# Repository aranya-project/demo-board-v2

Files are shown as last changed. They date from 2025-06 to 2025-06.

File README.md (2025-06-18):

# SpiderOak Demo V2 Board

This is a demonstration board for [Aranya
Embedded](https://github.com/aranya-project/aranya-embedded) built around the
ESP32-S3. It provides various peripheral options used by the [Aranya Embedded
demo](https://github.com/aranya-project/aranya-embedded/crates/demo-esp32-s3/).

## Board View

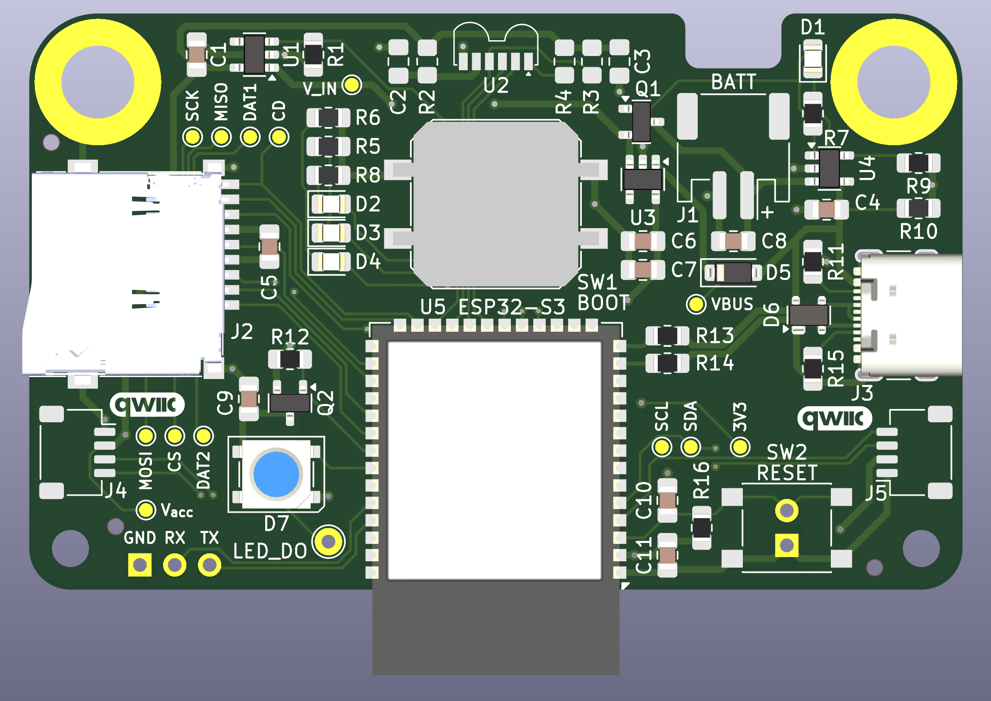
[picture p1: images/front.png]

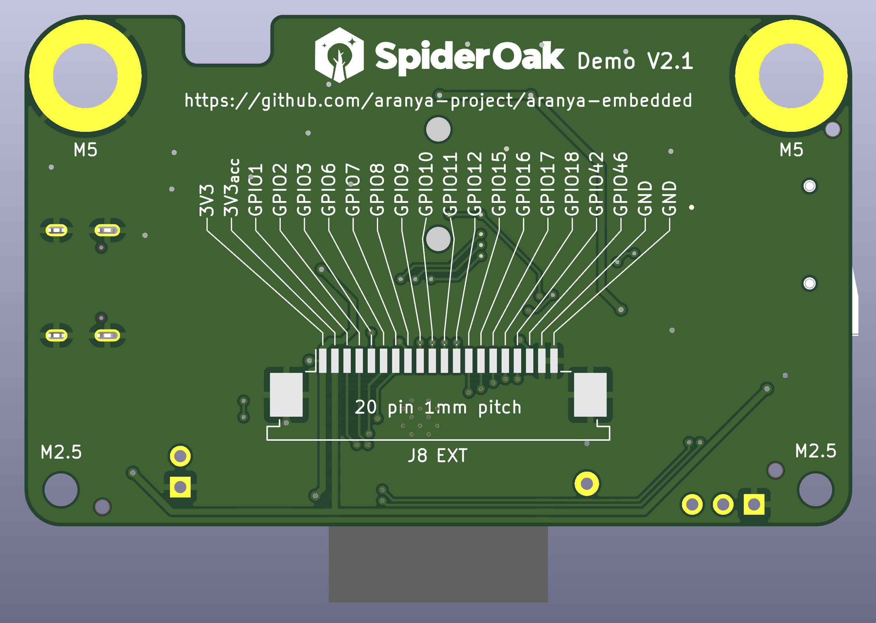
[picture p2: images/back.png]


## Assembly Options

The IR transceiver U2 is necessary if you intend ot use IR networking. It uses
the Vishay TFBS4711 which is somewhat pricey, so it has not been included by
default.

The battery jack is a 2mm pitch JST PH connector, and the Qwiic connectors are
1mm pitch JST SH connectors. The RGB LED is a WS2812 5mm LED module. The SD card
slot is a SameSky MSD-4-A, and the USB jack is a GCT USB4105. If you search
around you will find many alternatives for these as they are very commonly used.

A footprint is provided but not populated for reset switch - a SMD 6mm tactile
switch (Omron B3FS or similar). Likewise there is an unpopulated 20pin expansion
header on the back - details on that [below](#test-points-and-expansion).

## Power

Input power comes from either the battery or the USB input. A schottky diode and
a P-channel MOSFET (D5 and Q1) switch power between them and prevent USB power
from backfeeding into the battery. The battery is charged by a standard 500mA
5-pin single-cell lithium linear charge controller (TPS4054/MCP73831/etc), and
LED D1 will light when charging is complete.

The ESP32 is powered by a primary 3.3V regulator (the TLV74333), and all other
devices (IR transceiver, SD card slot, and any Qwiic accessories) are powered
by a secondary 3.3V regulator enabled by a high output on GPIO 47.

Separately, power to the RGB LED is switched via an open drain output on GPIO
40. This pin must be brought low to turn on the P-channel MOSFET controlling
power to the LED. The LED power is connected to input power (either the USB or
battery) directly, so it is not controlled by the accessory power regulator.

### Pin Summary

| GPIO Pin | Function | Operation |
|---|---|---|
| 47 | Accessory power enable | output, active high |
| 40 | LED power enable | open drain output, active low |

## IR Transceivers

IR1 is connected to UART1 TX/RX on pins on GPIOs 13 and 14, respectively. The IR
transceiver has to be enabled with a low output on GPIO 21.

Enabling IrDA mode requires setting `UART_IRDA_EN` in `UART_CONF0_REG`.
Additionally, to transmit, you need to set `UART_IRDA_TX_EN`. By default, IrDA
mode is half duplex, and `UART_IRDA_TX_EN` needs to be toggled to switch between
transmit and receive modes. To enable both transmit and receive at the same
time, which will echo all transmitted data through the RX line, set
`UART_IRDA_DPLX`.

For reasons I don't understand, the only thing that can be set via IDF APIs is
enabling IrDA mode. All of the other IrDA settings are not available via IDF
APIs, so you will likely have to twiddle the registers directly. In C, this can
be done by including `soc/uart_struct.h` and using the bitfield structs
provided. e.g.

```
UART1.conf0.irda_dplx = 1;
```

### Pin Summary

| GPIO Pin | Function | Operation |
|---|---|---|
| 13 | Transmit | output |
| 14 | Receive | input |
| 21 | Enable | output, active low |

## Micro SD

The SD card is connected to SPI such that it should be usable directly
through the IOMUX on IOs 35, 36, and 37. CS is connected to GPIO 38.
The slot has card detect functionality, which is connected to GPIO 48.

Additionally, DAT1 and DAT2 (only used in SD mode) are connected to
GPIOs 45 and 39, respectively, so you should theoretically be able to
enable 4-bit SD through the SD/MMC controller.

### Pin Summary (SPI mode)

| GPIO Pin | Function | Operation |
|---|---|---|
| 36 | SCK | output |
| 35 | MOSI | output |
| 37 | MISO | input |
| 38 | CS | output |

### Pin Summary (SD 1-bit mode)

| GPIO Pin | Function | Operation |
|---|---|---|
| 36 | CLK | output |
| 35 | CMD | input/output |
| 37 | DAT0 | input/output |
| 38 | CD | input |

### Pin Summary (SD 4-bit mode)

| GPIO Pin | Function | Operation |
|---|---|---|
| 36 | CLK | output |
| 35 | CMD | input/output |
| 37 | DAT0 | input/output |
| 45 | DAT1 | input/output |
| 39 | DAT2 | input/output |
| 38 | DAT3 | input/output |

### Pin Summary (card detect)

| GPIO Pin | Function | Operation |
|---|---|---|
| 48 | card detect | input, pull-up, active low |

## Debug LEDs

Three LEDs are hooked up to GPIOs 10-12, and can be used for any purpose.

### Pin Summary

| GPIO Pin | Function | Operation |
|---|---|---|
| 10 | Debug LED 1 | output, active high |
| 11 | Debug LED 2 | output, active high |
| 12 | Debug LED 3 | output, active high |

## Test points and expansion

The unused GPIOs 1-3, 6-9, 15-18, 42, and 46; the debug LED GPIOs 10-12; as
well as the main and accessory 3.3V regulators; and GND are broken out via a
20-pin 1mm pitch flat flex footprint on the back. You can either install a flat
flex connector or wire directly to the pads.

Test points are provided for VBUS (USB power), V_IN (OR'd power between VBUS and
VBATT), main 3V3, V<sub>acc</sub> (accessory power), SCL/SDA connected to the
Qwiic ports, and SCK, MOSI, MISO, CS, DAT1, DAT2 and CD on the SD card slot.

A three-pin 0.1" header is available for TX, RX, and GND for UART0, and a single
pin header is available for the DO pin on the WS2812 LED module. There are also
0.1" pin headers for the reset switch inside the tactile switch footprint.

## Mechanical

The board is 68mm wide and 42mm tall (2.68 x 1.66 inches). The ESP32-S3 module's
antenna hangs off of the bottom of the board, making the full height 48.4mm
(1.91 inches).

At the top are two M5 sized plated holes meant to accomodate lanyard hooks. They
are centered 5mm from the edges. At the bottom are two more M2.5 holes for any
other mounting needs, centered 3mm from the edges.

A 7x4mm cutout is provided near the battery connector in the top right of the
board. This allows any battery cables to be routed below the board even if the
board is mounted flush against a case.

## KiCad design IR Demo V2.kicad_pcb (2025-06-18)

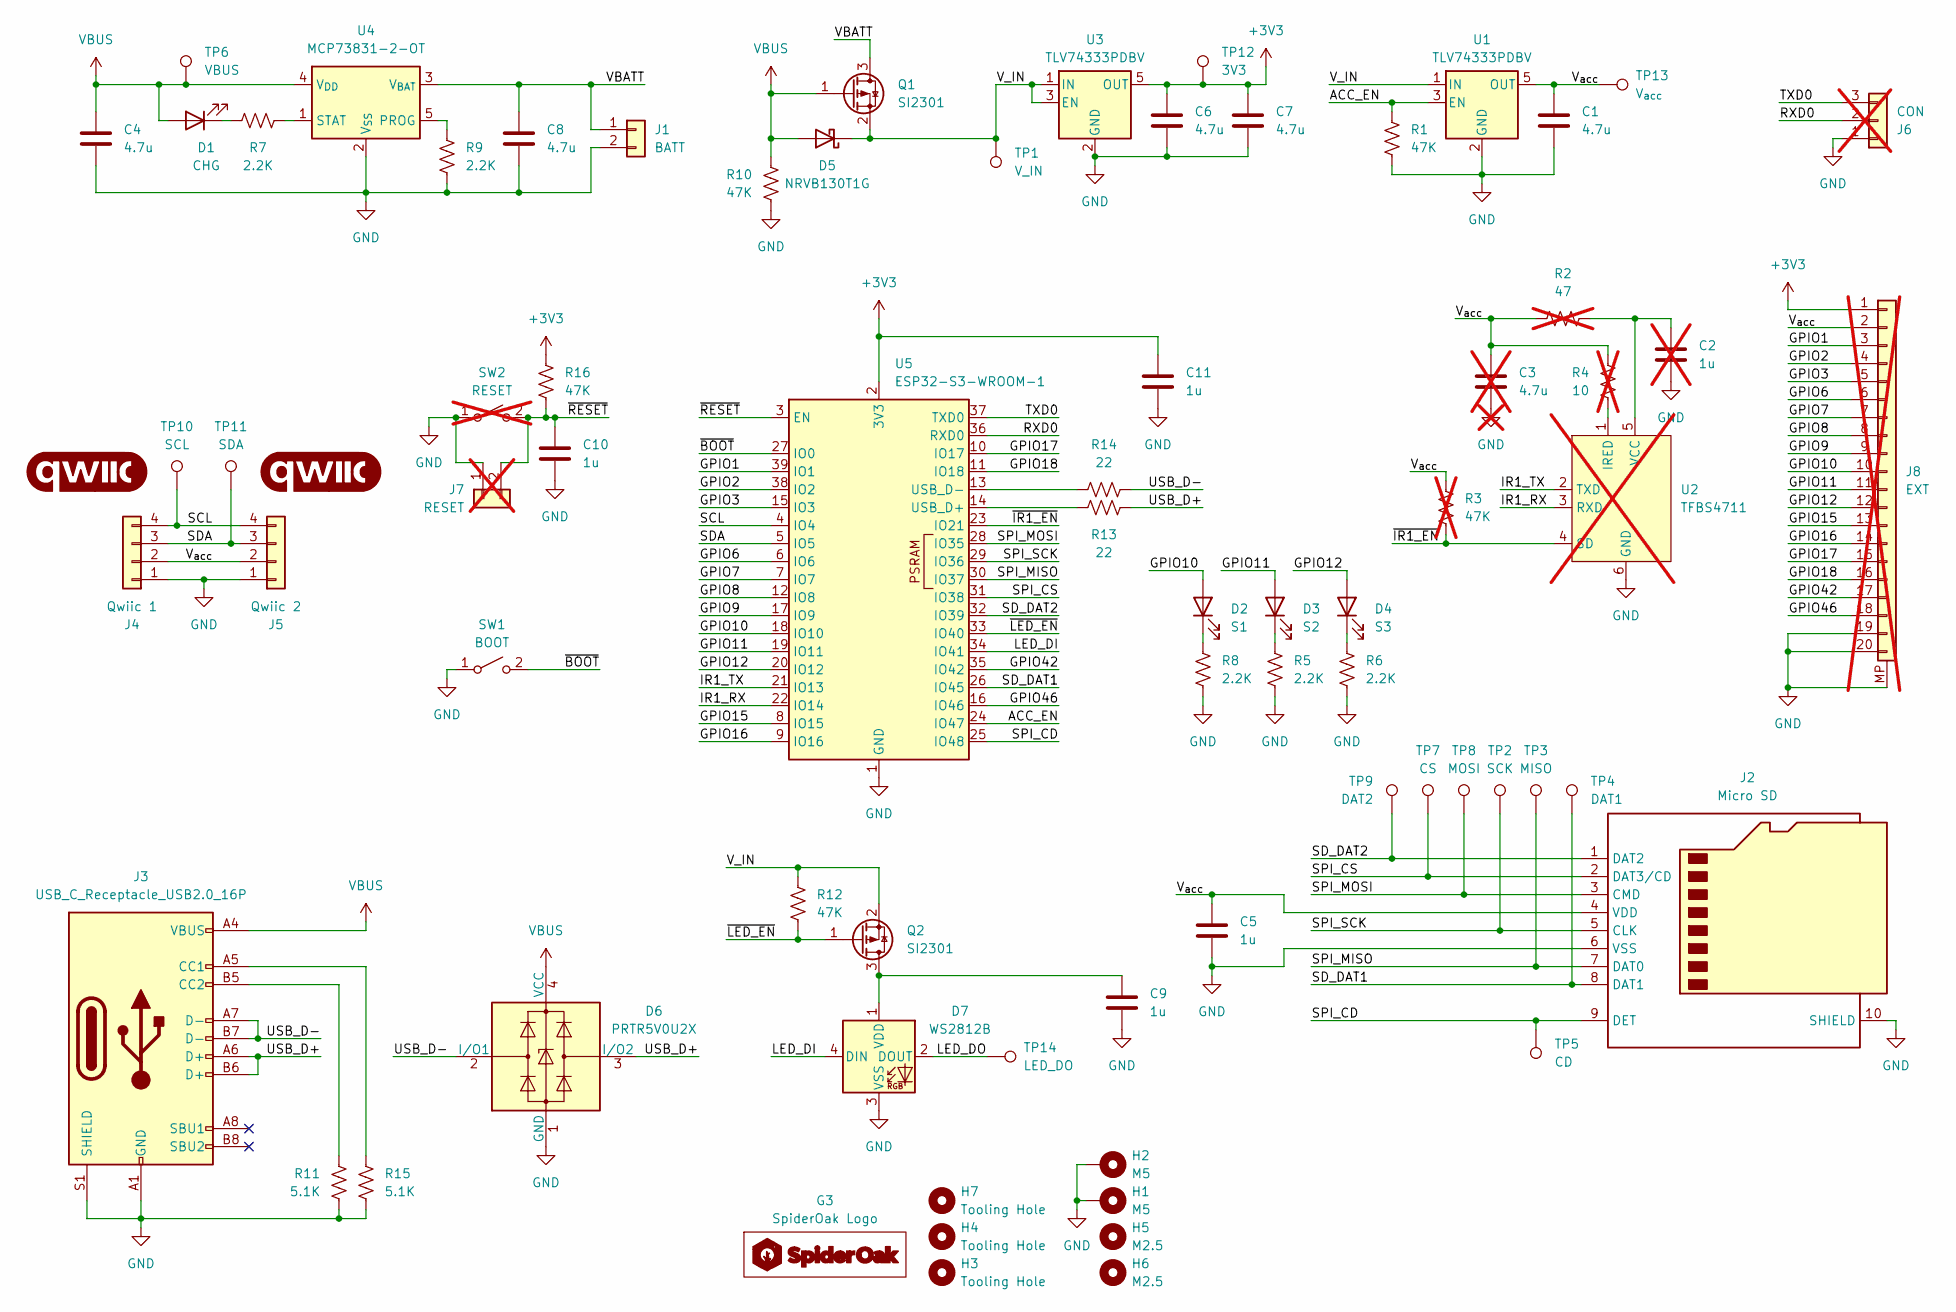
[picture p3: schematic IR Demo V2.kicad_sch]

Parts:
C1, C4, C6, C7, C8: 4.7u; C_0805_2012Metric_Pad1.18x1.45mm_HandSolder; MPN CL21A475KPFNNNG; LCSC PN C1779
C2: 1u; C_0805_2012Metric_Pad1.18x1.45mm_HandSolder; MPN CL21B105KBFNNNE; not fitted
C3: 4.7u; C_0805_2012Metric_Pad1.18x1.45mm_HandSolder; MPN CL21A475KPFNNNG; not fitted
C5, C9, C10, C11: 1u; C_0805_2012Metric_Pad1.18x1.45mm_HandSolder; MPN CL21B105KBFNNNE; LCSC PN C28323
D1: CHG; LED_0805_2012Metric; MPN XL-2012SURC; LCSC PN C965812
D2: S1; LED_0805_2012Metric; MPN XL-2012SURC; LCSC PN C965812
D3: S2; LED_0805_2012Metric; MPN XL-2012SURC; LCSC PN C965812
D4: S3; LED_0805_2012Metric; MPN XL-2012SURC; LCSC PN C965812
D5: NRVB130T1G; D_SOD-123; MPN NRVB130T1G; LCSC PN C917121
D6: PRTR5V0U2X; SOT-143; MPN PRTR5V0U2X; LCSC PN C558444
D7: WS2812B; LED_WS2812B_PLCC4_5.0x5.0mm_P3.2mm
G1, G2: qwiic_Logo; qwiic_5.5mm
G3: SpiderOak Logo; SpiderOak_Logo
H1, H2: M5; MountingHole_5.3mm_M5_DIN965_Pad
H3, H4, H7: Tooling Hole; ToolingHole_1.152mm
H5, H6: M2.5; MountingHole_2.7mm_M2.5
J1: BATT; JST_PH_S2B-PH-SM4-TB_1x02-1MP_P2.00mm_Horizontal; MPN WAFER-PH2.0-2PWB; LCSC PN C3029440
J2: Micro SD; MSD-4-A; MPN MSD-4-A; LCSC PN C5454948
J3: USB_C_Receptacle_USB2.0_16P; USB_C_Receptacle_GCT_USB4105-xx-A_16P_TopMnt_Horizontal; MPN USB4105; LCSC PN C2988369
J4: Qwiic 1; JST_SH_SM04B-SRSS-TB_1x04-1MP_P1.00mm_Horizontal; MPN WAFER-SH1.0-4PWB; LCSC PN C3029343
J5: Qwiic 2; JST_SH_SM04B-SRSS-TB_1x04-1MP_P1.00mm_Horizontal; MPN WAFER-SH1.0-4PWB; LCSC PN C3029343
J6: CON; PinHeader_1x03_P2.54mm_Vertical; not fitted
J7: RESET; PinHeader_1x02_P2.54mm_Vertical; not fitted
J8: EXT; TE_2-84953-0_1x20-1MP_P1.0mm_Horizontal; not fitted
Q1, Q2: SI2301; SOT-23; MPN SI2301; LCSC PN C42456911
R1, R10, R12, R16: 47K; R_0805_2012Metric_Pad1.20x1.40mm_HandSolder; MPN RC0805FR-0747KL; LCSC PN C126351
R2: 47; R_0805_2012Metric_Pad1.20x1.40mm_HandSolder; MPN RC0805FR-0722RL; not fitted
R3: 47K; R_0805_2012Metric_Pad1.20x1.40mm_HandSolder; MPN RC0805FR-0747KL; not fitted
R4: 10; R_0805_2012Metric_Pad1.20x1.40mm_HandSolder; MPN RC0805FR-0710RL; not fitted
R5, R6, R7, R8, R9: 2.2K; R_0805_2012Metric_Pad1.20x1.40mm_HandSolder; MPN RC0805FR-072K2L; LCSC PN C114561
R11, R15: 5.1K; R_0805_2012Metric_Pad1.20x1.40mm_HandSolder; MPN RC0805FR-075K1L; LCSC PN C84375
R13, R14: 22; R_0805_2012Metric_Pad1.20x1.40mm_HandSolder; MPN RC0805FR-0722RL; LCSC PN C107702
SW1: BOOT; SW_Push_1P1T_NO_CK_PTS125Sx43PSMTR; MPN TS-1003S-05026; LCSC PN C455219
SW2: RESET; SW_SPST_PTS645; not fitted
TP1: V_IN; TestPoint_Pad_D1.0mm
TP2: SCK; TestPoint_Pad_D1.0mm
TP3: MISO; TestPoint_Pad_D1.0mm
TP4: DAT1; TestPoint_Pad_D1.0mm
TP5: CD; TestPoint_Pad_D1.0mm
TP6: VBUS; TestPoint_Pad_D1.0mm
TP7: CS; TestPoint_Pad_D1.0mm
TP8: MOSI; TestPoint_Pad_D1.0mm
TP9: DAT2; TestPoint_Pad_D1.0mm
TP10: SCL; TestPoint_Pad_D1.0mm
TP11: SDA; TestPoint_Pad_D1.0mm
TP12: 3V3; TestPoint_Pad_D1.0mm
TP13: V_{acc}; TestPoint_Pad_D1.0mm
TP14: LED_DO; TestPoint_THTPad_D2.0mm_Drill1.0mm
U1, U3: TLV74333PDBV; SOT-23-5; MPN TLV74333PDBVR; LCSC PN C408972
U2: TFBS4711; MPN Vishay TFBS4711; not fitted
U4: MCP73831-2-OT; SOT-23-5; MPN TP4054; LCSC PN C5381776
U5: ESP32-S3-WROOM-1; MPN ESP32-S3-WROOM-1-N4R2; LCSC PN C2913203

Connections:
+3V3: C6.1, C7.1, C11.1, J8.1, R16.1, TP12.1, U3.5 (OUT), U5.2 (3V3)
/ACC_EN: R1.1, U1.3 (EN), U5.24 (IO47)
/GPIO1: J8.3, U5.39 (IO1)
/GPIO2: J8.4, U5.38 (IO2)
/GPIO3: J8.5, U5.15 (IO3)
/GPIO6: J8.6, U5.6 (IO6)
/GPIO7: J8.7, U5.7 (IO7)
/GPIO8: J8.8, U5.12 (IO8)
/GPIO9: J8.9, U5.17 (IO9)
/GPIO10: D2.2 (A), J8.10, U5.18 (IO10)
/GPIO11: D3.2 (A), J8.11, U5.19 (IO11)
/GPIO12: D4.2 (A), J8.12, U5.20 (IO12)
/GPIO15: J8.13, U5.8 (IO15)
/GPIO16: J8.14, U5.9 (IO16)
/GPIO17: J8.15, U5.10 (IO17)
/GPIO18: J8.16, U5.11 (IO18)
/GPIO42: J8.17, U5.35 (IO42)
/GPIO46: J8.18, U5.16 (IO46)
/IR1_RX: U2.3 (RXD), U5.22 (IO14)
/IR1_TX: U2.2 (TXD), U5.21 (IO13)
/LED_DI: D7.4 (DIN), U5.34 (IO41)
/LED_DO: D7.2 (DOUT), TP14.1
/RXD0: J6.2, U5.36 (RXD0)
/SCL: J4.4, J5.4, TP10.1, U5.4 (IO4)
/SDA: J4.3, J5.3, TP11.1, U5.5 (IO5)
/SD_DAT1: J2.8 (DAT1), TP4.1, U5.26 (IO45)
/SD_DAT2: J2.1 (DAT2), TP9.1, U5.32 (IO39)
/SPI_CD: J2.9 (DET), TP5.1, U5.25 (IO48)
/SPI_CS: J2.2 (DAT3/CD), TP7.1, U5.31 (IO38)
/SPI_MISO: J2.7 (DAT0), TP3.1, U5.30 (IO37)
/SPI_MOSI: J2.3 (CMD), TP8.1, U5.28 (IO35)
/SPI_SCK: J2.5 (CLK), TP2.1, U5.29 (IO36)
/TXD0: J6.3, U5.37 (TXD0)
/USB_D+: D6.3 (I/O2), J3.A6 (D+), J3.B6 (D+), R13.2
/USB_D-: D6.2 (I/O1), J3.A7 (D-), J3.B7 (D-), R14.2
/VBATT: C8.1, J1.1, Q1.3 (D), U4.3 (V_{BAT})
/V_IN: D5.1 (K), Q1.2 (S), Q2.2 (S), R12.1, TP1.1, U1.1 (IN), U3.1 (IN), U3.3 (EN)
/V_{acc}: C1.1, C3.1, C5.1, J2.4 (VDD), J4.2, J5.2, J8.2, R2.1, R3.1, R4.1, TP13.1, U1.5 (OUT)
/~BOOT: SW1.2 (B), U5.27 (IO0)
/~IR1_EN: R3.2, U2.4 (SD), U5.23 (IO21)
/~LED_EN: Q2.1 (G), R12.2, U5.33 (IO40)
/~RESET: C10.1, J7.2, R16.2, SW2.2 (B), U5.3 (EN)
GND: C1.2, C2.2, C3.2, C4.2, C5.2, C6.2, C7.2, C8.2, C9.2, C10.2, C11.2, D6.1 (GND), D7.3 (VSS), H1.1, H2.1, J1.2, J2.6 (VSS), J2.10 (SHIELD), J3.A1 (GND), J3.A12 (GND), J3.B1 (GND), J3.B12 (GND), J3.S1 (SHIELD), J4.1, J5.1, J6.1, J7.1, J8.19, J8.20, J8.MP, R1.2, R5.2, R6.2, R8.2, R9.2, R10.2, R11.2, R15.2, SW1.1 (A), SW2.1 (A), U1.2 (GND), U2.6 (GND), U3.2 (GND), U4.2 (V_{SS}), U5.1 (GND), U5.40 (GND), U5.41 (GND)
unnamed: D1.1 (K), R7.1
unnamed: D2.1 (K), R8.1
unnamed: D3.1 (K), R5.1
unnamed: D4.1 (K), R6.1
unnamed: C9.1, D7.1 (VDD), Q2.3 (D)
unnamed: J3.A5 (CC1), R15.1
unnamed: J3.B5 (CC2), R11.1
unnamed: R4.2, U2.1 (IRED)
unnamed: C2.1, R2.2, U2.5 (VCC)
unnamed: R9.1, U4.5 (PROG)
unnamed: R7.2, U4.1 (STAT)
unnamed: R13.1, U5.14 (USB_D+)
unnamed: R14.1, U5.13 (USB_D-)
VBUS: C4.1, D1.2 (A), D5.2 (A), D6.4 (VCC), J3.A4 (VBUS), J3.A9 (VBUS), J3.B4 (VBUS), J3.B9 (VBUS), Q1.1 (G), R10.1, TP6.1, U4.4 (V_{DD})

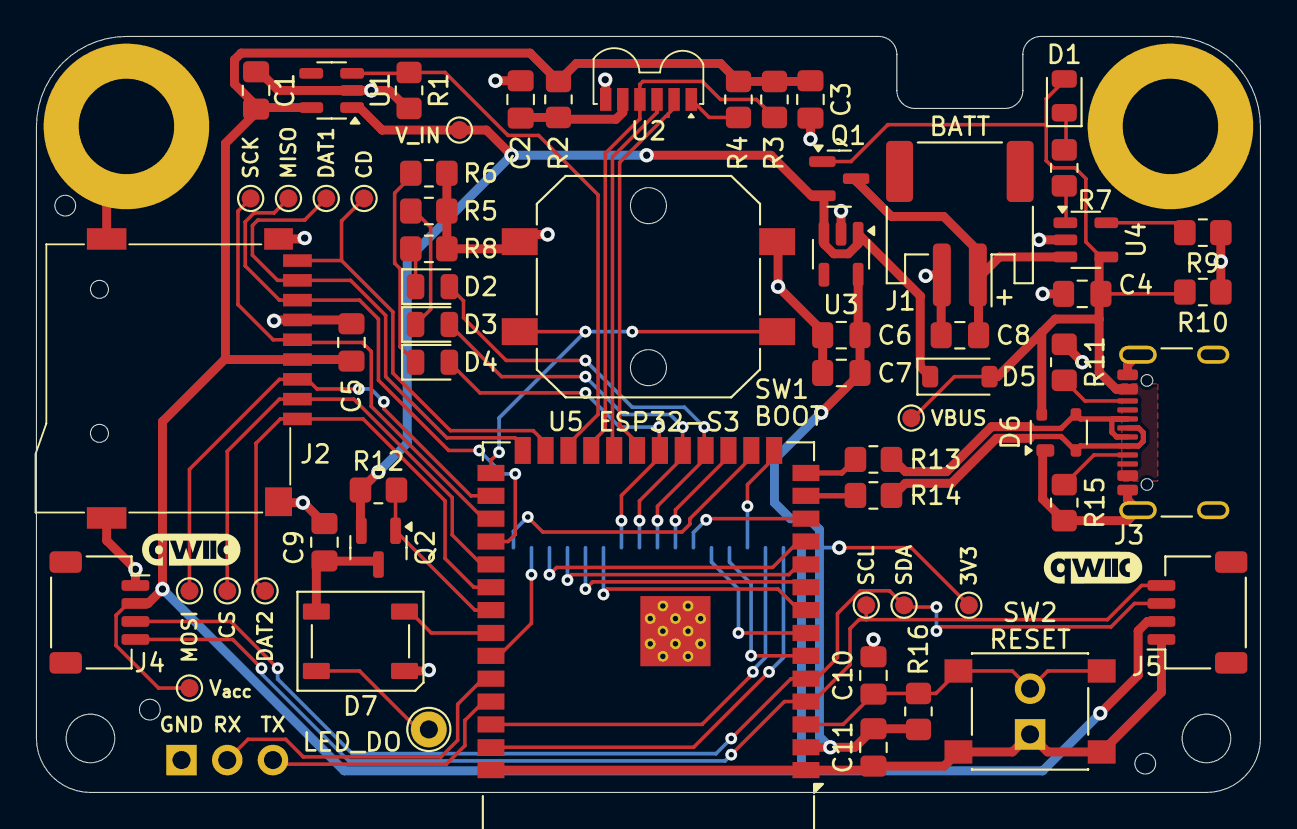
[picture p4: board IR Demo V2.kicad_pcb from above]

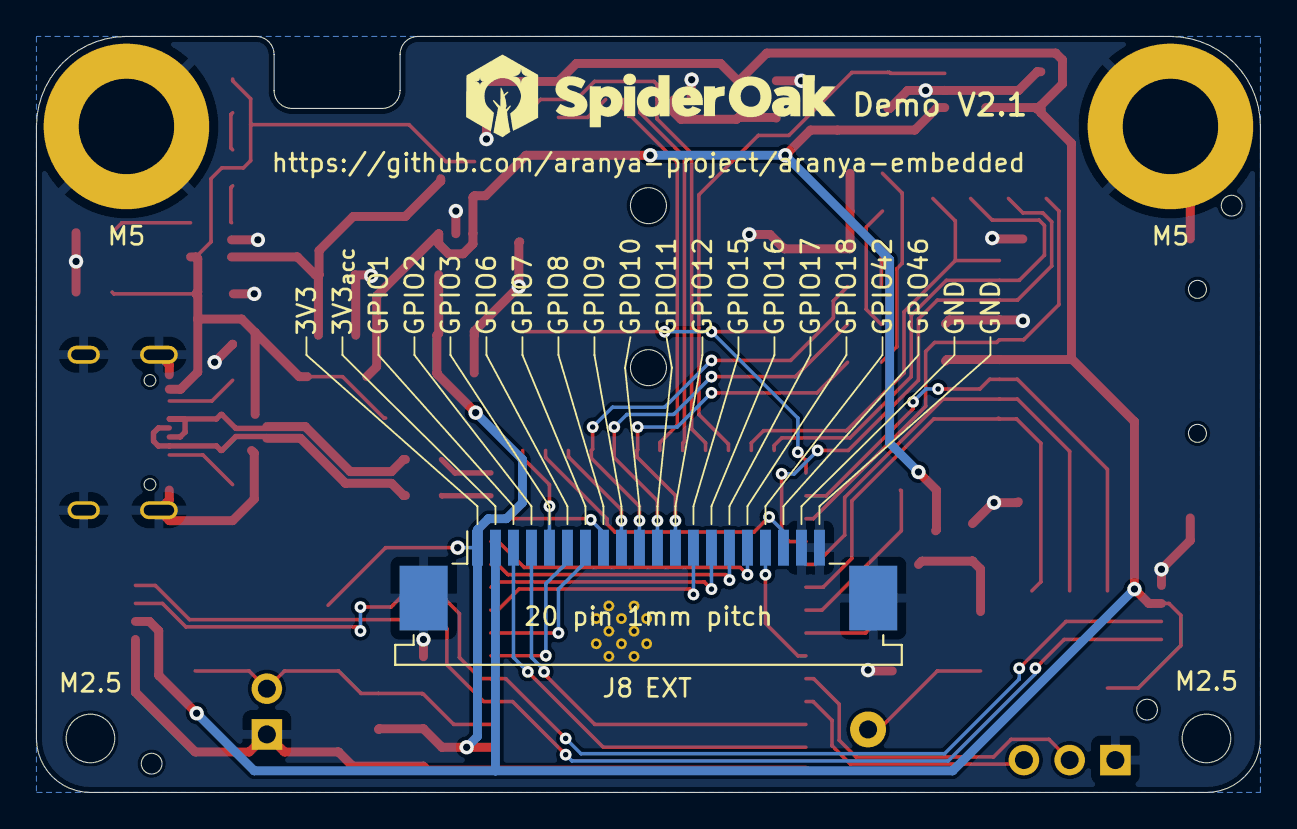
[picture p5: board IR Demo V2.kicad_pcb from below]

Board: 2 copper layers, 68.0 x 42.0 mm, 75 parts (2 on the bottom side), 57 nets.
